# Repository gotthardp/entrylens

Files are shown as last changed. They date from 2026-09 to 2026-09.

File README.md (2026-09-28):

# Entrylens

A door-mounted people-counting sensor using a VL53L8CX time-of-flight sensor and RAK3172 (STM32WLE5)
to detect and count people and report the counts over LoRaWAN (EU868).

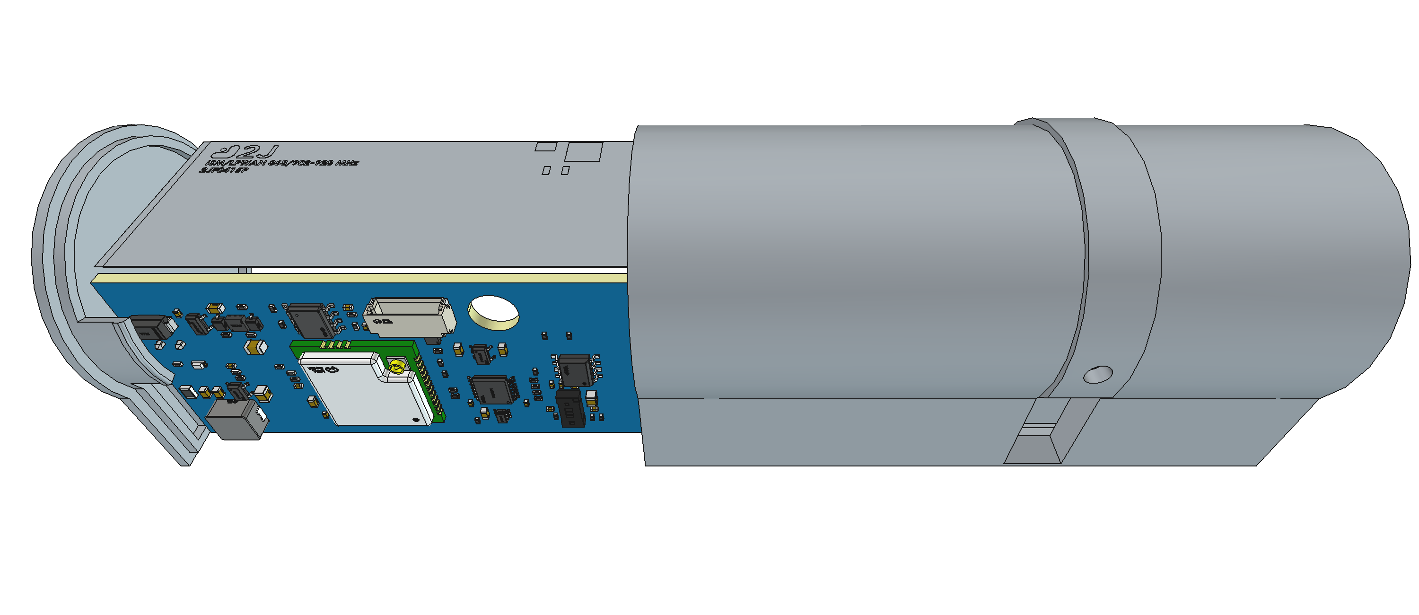
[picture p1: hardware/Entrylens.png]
Visualization


## Hardware

The design documentation is provided in [DESIGN.md](hardware/DESIGN.md).

The electronics are designed in [EasyEDA Pro](https://pro.easyeda.com) with assistance from
Claude Code (Anthropic), [pcba-design-skills](https://github.com/Keitark/pcba-design-skills), and
[pcb-checklist](https://github.com/azonenberg/pcb-checklist).

The enclosure is designed in [FreeCAD](https://www.freecad.org).

The PCB can be manufactured through [JLCPCB](https://jlcpcb.com), and the enclosure through
[JLC3DP](https://jlc3dp.com/). The reproduction cost is approximately USD 40 per unit in a small
production batch of approximately 20 units.

## Firmware

In development.

## License

Hardware design files are licensed under [CERN-OHL-W](https://cern-ohl.web.cern.ch).

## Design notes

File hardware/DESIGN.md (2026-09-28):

# Design

This document covers design intent, architecture, and components of the Entrylens sensor. Exact
passive values, pin assignments and net connectivity are in the netlist/BOM.

Visualization

## 1. Intended Use

Entrylens is an indoor people-counting sensor for museums and exhibition areas. One unit is
installed at each door opening; it counts pedestrian traffic and transmits the counts wirelessly
for occupancy calculation and analysis.

The device is intended for professional installation by technical personnel responsible for
building or museum technology.

It is an open-hardware reference design, intended to support subsequent conformity assessment and
reproduction for own use.

The target reproduction cost is about USD 40 per unit, assuming a small batch of about 20 units.

## 2. Usage

This section defines the deployment conditions, operating envelope and functional limitations of
the device. Sections 3-5 describe how they are met.

### 2.1 Deployment

The device is mounted centrally on the lower rear edge of the head jamb, opposite the door leaf,
and secured with 15 mm wide double-sided adhesive tape.

The aperture must not receive direct sunlight, as ambient infrared reduces the ranging accuracy.

The 45 degree field of view covers a 2.07 m wide strip at 250 cm mounting height; mounting lower
narrows it proportionally. The reference installation was tested on a double-leaf doorway, 250 cm
high and 130 cm wide.

The device is continuously powered over a two-wire cable from an external DC supply. The supply
must provide a SELV output, 5 V nominal, rated between 500 mA and 2 A; the 2 A maximum limits the
fault current in the cable. The cable may be up to 20 m long and must have 0.33 mm2 (22 AWG)
copper conductors, which keeps the input above the 3.5 V minimum. Copper-clad aluminium must not
be used.

Wireless network credentials are configured from a mobile application and transferred over NFC-V
(ISO/IEC 15693). The configuration is protected by a 64-bit password and remains accessible when
the device is unpowered.

### 2.2 Operation

The device continuously detects and counts people entering and leaving, using a distance-measuring
sensor; it captures no images or other visual data.

The device is designed for bidirectional traffic of individuals and groups of up to two people
abreast, walking at up to 1.5 m/s. Under the specified operating conditions the target counting
accuracy is 95 %.

The design service life is 10 years of continuous operation.

A two-colour (red/green) status LED, controlled by the MCU, is visible from outside the
enclosure. A red power LED is visible only with the lid removed.

The antenna must remain connected whenever the board is powered; powering the RAK3172 with the
U.FL connector unmated may damage its RF section.

### 2.3 Maintenance

No routine physical maintenance is required. Firmware updates and diagnostics can be performed
remotely where wireless connectivity is available.

### 2.4 Service

The debug/programming connector inside the enclosure gives access to detailed device status and is
used for troubleshooting, firmware updates and production programming. It is not connected during
normal operation.

The debug connector must not be used to power the device; the debugger's target power output must
be disabled.

Labelled test pads on the top side give probe access to +5V, +3V3, +1V8, the switched sensor
supply (+3V3_TOF, at the sensor), the eFuse FAULT signal and GND (two pads).

### 2.5 Operating environment

The device is designed for indoor use in ordinary environments such as museums and exhibition
spaces. It is not intended for industrial environments or hazardous areas.

- Temperature: 0 to 40 C
- Relative humidity: 10 to 90 % RH, non-condensing
- Vibration/shock: none expected
- Ingress protection: none declared

## 3. Mechanical

### 3.1 Composition

The device is composed of:
- an enclosure made from Nylon PA12S, modelled in `EntrylensHousing.FCStd`
- the PCB, described in Section 4
- a light pipe (FIX-LEMB3-5V0-F) that makes the red/green status LED visible from outside
- an 868 MHz antenna board (2JF0415P), whose 100 mm U.FL/IPEX cable connects directly to the
  RAK3172

### 3.2 Arrangement

The enclosure is a compact cylinder, 85 mm x 40 mm, with a removable lid for access to the
electronics. There are no external antennas or other protruding parts; only the power cable
enters, through a strain relief.

The VL53L8CX looks vertically down through a tapered aperture in the enclosure wall.

The 82 mm x 29 mm PCB and the antenna board are mounted perpendicular to each other. Both are
retained by rails that engage the clear keepout areas along the long edges of the PCB, rather than
by mounting holes or screws.

A 6 mm non-plated hole in the PCB gives clearance for the U.FL/IPEX cable from the RAK3172 to the
antenna board.

## 4. Hardware

### 4.1 Architecture

The PCB integrates the following functional blocks:
- Power input
  - 2-pin JST XH connector (B2B-XH-A(LF)(SN))
  - Input protection chain, described in Section 4.2
  - 3.3 V buck converter (TLV62569)
  - Ferrite bead (MPZ2012S331ATD25) filtering high-frequency noise
- MCU and LoRaWAN transceiver module (RAK3172, based on STM32WLE5)
- Debug/programming interface
  - 7-pin JST SR connector (SM07B-SRSS-TB)
  - ESD protection (GMF05LC-HSF)
- 4 Mbit NOR flash (P25Q40SH)
- Voltage and logic level conversion to 1.8 V
  - 1.8 V LDO regulator (MIC5504) with output discharge, switched by the MCU
  - 4-channel level shifter (LSF0204)
- ToF ranging sensor (VL53L8CX)
  - AVDD load switch (TPS22919), switched by the MCU
- Dynamic NFC/RFID tag (ST25DV04KC) with a 512-byte EEPROM
  - Antenna coil on PCB (ST25DV_Discovery_ANT_C6)
- Two LEDs: a power indicator (KT-0603R) and a status indicator (LTST-C295KGKRKT)

The LoRa antenna is placed away from the NFC antenna coil to minimize coupling.

### 4.2 Power

The device is powered over a cable up to 20 m long, so the input stage is built to survive
miswiring and cable transients. It operates from 3.5 to 5.5 V, which covers a 5 V supply's
tolerance, and withstands +/- 9 V of wrong polarity or overvoltage for at least 1 h.

The input protection chain, in order:

| Part | Function |
|---|---|
| SMAJ10CA | Input surge absorption |
| AO3401A | Reverse-polarity block |
| BZX384-C6V2 | AO3401A Vgs clamp |
| BZX384-C6V2 | Holds TPS25200 EN below its 7 V rating through the +/- 9 V withstand |
| TPS25200 | Overcurrent, overvoltage and overtemperature protection |

The TPS25200 EN pull-up is stronger than the datasheet value, so leakage cannot pull EN below its
threshold at 3.5 V in.

TPS25200 FAULT disables the TLV62569 during overcurrent, overtemperature or overvoltage lockout.
The FAULT pull-up sits on the TPS25200 output rather than on +3V3, so losing that output also
removes the TLV62569 enable, even if FAULT fails to assert.

| Rail | Nominal | Worst case | Bound by |
|---|---|---|---|
| +5V | clamped 5.25 - 5.55 V | | TPS25200 output clamp |
| +3V3 | 3.288 V | 3.212 - 3.365 V | VL53L8CX AVDD 3.13 - 3.47 V |
| +3V3_TOF | | 3.178 - 3.422 V | VL53L8CX AVDD 3.13 - 3.47 V |
| +1V8 | 1.800 V | 1.703 - 1.858 V | VL53L8CX 1.62 - 1.98 V |

The +3V3_TOF worst case adds the TLV62569 light-load rise (+1.7 %, typical curve) and the drops
through the ferrite bead and the TPS22919; the TLV62569 feedback resistors are therefore 0.1 %
parts. The +1V8 worst case uses the MIC5504 +/- 3 % over temperature plus its full-range load and
line regulation.

The RAK3172 monitors +5V through an ADC divider.

The +1V8 rail is enabled by an MCU GPIO with a pull-down, so it stays off until firmware enables
it and can be cycled. When disabled, the MIC5504 actively discharges the rail. Its turn-on time
(125 us max at 1 uF) meets the VL53L8CX minimum supply slew rate; the rail carries more than 1 uF
including local decoupling, so the ramp is confirmed at bring-up.

Firmware must configure the 1.8 V side GPIOs before enabling the rail, because the LSF0204 has no
internal pull-ups.

FAULT is not asserted while only the TPS25200 output clamp is engaged. Between the clamp and the
overvoltage lockout (6.8 - 8.45 V in), the device keeps running with +5V held at 5.4 V. The
TLV62569 input then reaches 5.55 V, over its 5.5 V recommended maximum but inside its 6 V limit;
this is accepted for a fault condition.

| Input at lockout | TPS25200 dissipation | TJ at 40 C |
|---|---|---|
| 6.8 V  | 0.30 W | 60 C |
| 8.45 V | 0.66 W | 84 C |

The device is continuously active in normal operation and does not use deep-sleep modes.

The peak current budget below treats VL53L8CX ranging and RAK3172 transmission as concurrent:

| Component | +3V3 | +1V8 |
|---|---|---|
| VL53L8CX | 60 mA  | 100 mA |
| RAK3172 | 120 mA | |
| P25Q40SH | 4 mA | |
| ST25DV04KC | 1 mA | |
| KT-0603R | 12 mA  | |
| LTST-C295KGKRKT | 22 mA  | |
| Total | 219 mA | 100 mA |

The +3V3 rail supplies 319 mA including +1V8, against a TPS25200 current limit of 428 mA
(366 - 495 mA).

At its 100 mA share the MIC5504 runs at TJ 78 - 82 C, against a 125 C limit.

### 4.3 MCU (RAK3172)

BOOT0 is not connected, and the design does not rely on RAK's undocumented internal pull-down.
Instead, option bytes nSWBOOT0 = 0 and nBOOT0 = 1, set during production programming
(Section 2.4), select boot from main flash. This disables the bootloader fallback; recovery uses
SWD.

The STM32WLE5 independent watchdog (IWDG) reboots the device if the firmware becomes unresponsive.

Brown-out reset (BOR) stays enabled. Below the BOR threshold the MCU is held in reset until the
supply recovers and then boots normally, so short interruptions and undervoltage give a clean
restart rather than degraded operation.

### 4.4 Debug/programming interface

Debugging and programming use a 7-pin JST SR connector. Its pinout is also printed on the bottom
silkscreen:

- 1: UART_RX
- 2: UART_TX (MCU output)
- 3: GND
- 4: NRST
- 5: SWCLK
- 6: SWDIO
- 7: VREF out

Either an ST-LINK or a DAPLink debugger can be used. UART2 alongside SWD provides the status access
of Section 2.4.

Pin 7 is the debugger's voltage reference only; the board is always powered from its power
connector.

The connector signals are protected as follows:

| Part | Function |
|---|---|
| GMF05LC-HSF | ESD protection of pins 1, 2 and 4-6 |
| Series resistor | Current limiting on pin 7 (VREF out) |

### 4.5 External flash (P25Q40SH)

The flash stores the VL53L8CX firmware image and, during FOTA updates, the staged MCU application
image.

/WP and /HOLD are pulled high and not MCU-controlled, so hardware write protection is unavailable.

### 4.6 ToF sensor (VL53L8CX)

The detection field of view is 45 degrees horizontally and vertically.

The enclosure aperture has no cover glass, so no crosstalk calibration is required.

An ESD clearance area surrounds the sensor aperture, so the sensor decoupling capacitors sit at its
edge rather than next to the pins.

The sensor is used in I2C mode, with the bus at 1 MHz.

The ST25DV04KC requires Rbus x Cbus below 150 ns at 1 MHz. With the fitted pull-ups this allows
45 pF on the MCU side of the LSF0204, so those traces must be kept short.

To fully reset the sensor, the MCU switches off both AVDD (through the TPS22919 load switch) and
+1V8. Both rails are actively discharged, so the 10 ms off time of UM3109 applies.

The footprint uses plain rectangular pads and deviates from ST's recommendation in two places.
Pads B1 and B7 are 0.500 mm instead of 0.535 +/- 0.030 mm, 0.005 mm beyond tolerance, which is
accepted as negligible. The thermal pad has 5 stitched vias instead of the 8 shown in AN5897,
because more do not fit the fabricator's via rules.

### 4.7 NFC (ST25DV04KC)

Energy harvesting is disabled in the device configuration, and V_EH is intentionally left
unconnected.

The antenna is a PCB coil following the ST25DV_Discovery_ANT_C6 reference design
(ANT-1-6-ST25DV):
- Turns: 15
- Size: 18.5 mm x 22.7 mm
- Trace width / spacing: 0.2 mm / 0.2 mm
- Copper: 1 oz (35 um)
- Copper beneath the coil on other layers: none
- Inductance at 13.56 MHz: 4.71 uH

### 4.8 PCB

The board has 4 layers, stacked Signal / GND / Power / Signal in JLCPCB's standard stackup: one
0.21 mm sheet of 7628 prepreg under each outer layer and a 1.065 mm core between the planes.

No trace needs controlled impedance. The 868 MHz signal leaves through the RAK3172's IPEX
connector, and the 13.56 MHz NFC coil is electrically short, so it acts as a lumped inductor.

Fabrication:
- Material: FR-4 TG135
- Thickness: 1.6 mm
- Copper: 1 oz on outer layers, as the NFC coil requires, and 0.5 oz on inner layers
- Surface finish: HASL with lead
- Vias: epoxy filled and capped, so thermal-pad vias do not draw solder from the joint
- Marking: 5 x 5 mm 2D barcode with a serial number ABCDE_0001

Assembly is SMT on the top side only; the power connector is through-hole and hand-soldered.

The VL53L8CX (MSL 3) package is not sealed, so assembly uses no-clean solder paste and no washing
(DS14161 12.6). The leaded HASL finish means leaded solder paste instead of ST's recommended
SAC305, accepted for its lower reflow peak.

Leaded solder is acceptable because RoHS does not apply (Section 6).

## 5. Software

Firmware is custom and bare-metal (no RUI3), built with STM32CubeIDE and programmed via SWD.

### 5.1 Bootloader

The bootloader checks whether a valid FOTA image is available in external flash. If so, it
installs the image and then boots the sensing application; an incomplete or invalid image is not
installed.

There is no rollback: a device that crashes immediately on boot after an update requires manual
maintenance.

### 5.2 Sensing application

The device operates as a LoRaWAN Class A device in the EU868 band. OTAA and ABP activation are
both supported; the choice is set via NFC provisioning.

Event counters are aggregated and uplinked within 5 minutes of a detection, subject to duty-cycle
limits. This window bounds the reporting latency while leaving duty-cycle margin for FOTA
downlinks.

The device keeps no synchronized wall-clock time, so events are associated with the network-server
reception timestamp rather than a precise local detection timestamp.

Counters are cumulative and volatile; no counter state is written to non-volatile memory. Any
reset or supply interruption restarts them at zero, and each uplink carries the cumulative value
and a reboot indicator so the network server can reconcile the discontinuity.

### 5.3 FOTA update

Firmware chunks received via LoRaWAN downlinks are staged in the P25Q40SH. Once a digital
signature has verified the image's authenticity and integrity, the bootloader is invoked to
install it.

## 6. Compliance

Entrylens units are built by the party that uses them, for its own use, so they are never placed
on the market (Commission Blue Guide on EU product rules, 2022/C 247/01, Section 2.3). Each unit
is only put into service, as defined in Directive 2014/53/EU (Radio Equipment Directive, RED),
Article 2(1)(11).

The RED still applies, as it also covers putting into service (RED Article 1(1)). Whoever puts a
unit into service takes on the manufacturer's responsibility for compliance and conformity
assessment (Blue Guide, Section 3.1).

Formal conformity assessment and testing have not yet been completed.

EMC immunity levels are not declared at design time; they are set at conformity assessment.
Instead, the power input is designed to tolerate what a 20 m indoor cable produces: hot-plug
ringing, coupled switching transients and miswiring.

The applicable RED essential requirements are:
- Article 3(1)(a): health and safety
- Article 3(1)(b): electromagnetic compatibility
- Article 3(2): effective and efficient use of radio spectrum

The RED Article 3(3)(d)-(f) cybersecurity requirements (Delegated Regulation (EU) 2022/30) do not
apply: the device operates on a LoRaWAN network with no internet connection and processes no
personal data.

Directive 2011/65/EU (RoHS) does not apply, because it restricts hazardous substances only in
equipment placed on the market (RoHS Article 4(1)).

Conformity is intended to be demonstrated with these harmonised standards:
- ETSI EN 300 220-2, applicable to the 863-870 MHz LoRa radio interface
- ETSI EN 300 330, applicable to the 13.56 MHz NFC interface
- ETSI EN 301 489-1 and EN 301 489-3, applicable to electromagnetic compatibility

EN IEC 62368-1 may be used as a supporting safety standard, subject to confirmation of its
applicability to the final equipment configuration.

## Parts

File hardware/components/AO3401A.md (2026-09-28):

# Pin requirements: AO3401A

- References:
  - Datasheet: `AO3401A.pdf`, "Absolute Maximum Ratings" and "Electrical Characteristics" tables
- Package / orderable variant this table applies to: SOT-23, AO3401A (P-channel MOSFET)

## Per-pin requirements

3-terminal part (Gate/Drain/Source MOSFET) - beyond identifying the three terminals in the
package pinout diagram, the datasheet does not assign a distinct requirement per pin.

## Electrical limits and consumption

| Parameter | Value | Conditions |
|---|---|---|
| Drain-source voltage (VDS) | -30 V | Absolute maximum |
| Gate-source voltage (VGS) | +/- 12 V | Absolute maximum |
| Continuous drain current (ID) | -4 A | Absolute maximum, TA = 25 degC |
| Continuous drain current (ID) | -3.2 A | Absolute maximum, TA = 70 degC |
| Pulsed drain current (IDM) | -27 A | Absolute maximum |
| Power dissipation (PD) | 1.4 W | TA = 25 degC |
| Power dissipation (PD) | 0.9 W | TA = 70 degC |
| Junction temperature | -55 to 150 degC | Absolute maximum |
| Drain-source breakdown voltage (BVDSS) | -30 V min | ID = -250 uA, VGS = 0 V |
| Gate threshold voltage (VGS(th)) | -0.5 / -0.9 / -1.3 V (min/typ/max) | VDS = VGS, ID = -250 uA |
| Static drain-source on-resistance (RDS(ON)) | 47 / 60 mOhm (typ/max) | VGS = -4.5 V, ID = -3.5 A |
| Static drain-source on-resistance (RDS(ON)) | 60 / 85 mOhm (typ/max) | VGS = -2.5 V, ID = -2.5 A |

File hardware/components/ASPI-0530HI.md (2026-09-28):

# Pin requirements: ASPI-0530HI-2R2M-T2

- References:
  - Datasheet: `ASPI-0530HI.pdf` (Abracon ASPI-0530HI series), "Electrical Specifications" table
- Package / orderable variant this table applies to: 5.7 x 5.3 x 3.0 mm molded power inductor,
  ASPI-0530HI-2R2M-T2 (2.2 uH, M = +/-20% tolerance, row for "ASPI-0530HI-2R2")

## Per-pin requirements

2-terminal part (power inductor) - the datasheet does not assign a distinct requirement per
terminal.

## Electrical limits and consumption

| Parameter | Value | Conditions |
|---|---|---|
| Inductance | 2.2 uH | +/- 20% tolerance |
| DC resistance (DCR), typical | 29.0 mOhm | |
| DC resistance (DCR), maximum | 35.0 mOhm | |
| Saturation current (Isat) | 9.0 A | Based on inductance change, dL/Lo <= -20% |
| Temperature-rise current (Irms) | 5.5 A | Based on 40 degC typical temperature rise |
| Maximum voltage | 30 V DC | |
| Operating temperature & humidity | -55 to 125 degC | Including self-generated heat |

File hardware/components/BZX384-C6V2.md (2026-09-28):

# Pin requirements: BZX384-C6V2

- References:
  - Datasheet: `BZX384_SER.pdf` (Nexperia BZX384 series, voltage regulator diodes), Rev. 4,
    1 January 2023. Pinning in Table 2, limiting values in Table 5, thermal characteristics in
    Table 6, per-type characteristics in Table 8 (row 6V2, selection C)
- Package / orderable variant this table applies to: SOD323 (SC-76), BZX384-C6V2,115 (C = the
  approximately +/-5 % tolerance selection)

## Per-pin requirements

| Pin | Function | Requirement |
|---|---|---|
| 1 | K, cathode | The marking bar indicates the cathode. |
| 2 | A, anode | |

## Electrical limits and consumption

| Parameter | Value | Conditions |
|---|---|---|
| Working voltage (VZ) | 5.80 to 6.60 V | IZ = 5 mA, Tj = 25 degC |
| Differential resistance (rdif) | 150 Ohm max / 10 Ohm max | IZ = 1 mA / IZ = 5 mA |
| Reverse current (IR) | 3 uA max | VR = 4 V |
| Temperature coefficient (SZ) | 0.4 to 3.7 mV/K | IZ = 5 mA |
| Forward voltage (VF) | 0.9 V max / 1.1 V max | IF = 10 mA / IF = 100 mA |
| Forward current (IF) | 250 mA | Limiting value |
| Non-repetitive peak reverse current (IZSM) | 6.0 A | tp = 100 us square wave, Tj = 25 degC prior to surge |
| Total power dissipation (Ptot) | 300 mW | Tamb <= 25 degC, FR4 PCB, standard footprint |
| Junction temperature (Tj) | 150 degC | Limiting value |
| Thermal resistance | 415 K/W junction to ambient, 110 K/W junction to solder point | In free air on FR4 / cathode tab |

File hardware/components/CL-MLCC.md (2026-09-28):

# Pin requirements: Samsung CL-series MLCCs

- References:
  - Datasheet: no local PDF. Samsung Electro-Mechanics publishes per-part data online at
    `https://weblib.samsungsem.com/mlcc/mlcc-ec-data-sheet.do?partNumber=<PART>`, where `<PART>`
    is the BOM's `Manufacturer Part` with its **trailing suffix letter removed** (the BOM's
    `CL21A226MAQNNNE` is queried as `CL21A226MAQNNN`).
- Package / orderable variant this table applies to: the 0402, 0603 and 0805 chip sizes listed.

## Per-pin requirements

2-terminal part - the datasheet assigns no distinct requirement per terminal.

## Part-number structure

`CL` `21` `A` `226` `M` `A` `Q` `NNN` `E`

| Field | Chars | Meaning | Codes seen |
|---|---|---|---|
| Series | `CL` | Samsung general-purpose MLCC | - |
| Case | 2 digits | EIA size | `05` = 0402, `10` = 0603, `21` = 0805 |
| Dielectric | 1 | Temperature characteristic | `A` = X5R, `B` = X7R, `C` = C0G |
| Capacitance | 3 | Two significant digits then decade exponent, in pF | `103` = 10 nF, `475` = 4.7 uF, `226` = 22 uF |
| Tolerance | 1 | EIA code | `J` = +/-5%, `K` = +/-10%, `M` = +/-20% |
| Rated voltage | 1 | | `Q` = 6.3 V, `P` = 10 V, `O` = 16 V, `A` = 25 V, `B` = 50 V |
| Thickness | 1 | | `5` = 0.50 mm, `8` = 0.80 mm, `Q` = 1.25 mm |
| Remainder | 4 | Not determined | `NNNC`, `NNNE`, `NRNC` observed |

So rated voltage is readable straight from the BOM's `Manufacturer Part` column without fetching
anything. Two traps: `Q` means 6.3 V in the voltage position but 1.25 mm in the thickness position
that follows it, and `A` and `B` mean dielectrics in one position and voltages in another.

This table was derived by decoding nine part numbers against their fetched data - the seven below
plus CL05C100JB5NNNC (10 pF C0G, the former C1, source of the `C` and `J` codes) and
CL10A475KO8NNNC (4.7 uF 16 V 0603, the former C16) - not transcribed
from a Samsung numbering guide. Every field is consistent across all nine, but codes outside those
listed are unverified - fetch the part rather than extrapolate.

## Electrical limits and consumption

Rated voltage is the figure worth pinning down: the BOM records capacitance and case size but not
voltage, and DC-bias derating scales with the fraction of rated voltage actually applied.

| Manufacturer Part | Value | Tol. | Dielectric | Case | Rated voltage |
|---|---|---|---|---|---|
| CL05B103KB5NNNC | 10 nF | +/-10% | X7R | 0402 | 50 V |
| CL05B104KO5NNNC | 100 nF | +/-10% | X7R | 0402 | 16 V |
| CL10A105KB8NNNC | 1 uF | +/-10% | X5R | 0603 | 50 V |
| CL10A226MQ8NRNC | 22 uF | +/-20% | X5R | 0603 | 6.3 V |
| CL10A106KP8NNNC | 10 uF | +/-10% | X5R | 0603 | 10 V |
| CL21A226MAQNNNE | 22 uF | +/-20% | X5R | 0805 | 25 V |
| CL21A475KAQNNNE | 4.7 uF | +/-10% | X5R | 0805 | 25 V |

The online datasheet states "Graphs for the item are not supported", so it publishes no DC-bias
curve. Rated voltage is therefore the only derating indicator the vendor provides.

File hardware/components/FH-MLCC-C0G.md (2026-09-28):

# Pin requirements: Fenghua C0G MLCCs

- References:
  - Datasheet: `MLCC-NPO.pdf` (Guangdong Fenghua, www.fenghua.com, "MLCC - NPO (COG)", 5 pages).
    The document carries no revision or date. How to Order (page 1), size code, capacitance and
    voltage table (page 3), dielectric characteristics and test methods (page 4)
- Package / orderable variant this table applies to: 0402 (1005 metric), 0402CG330J500NT (C1)

## Per-pin requirements

2-terminal part - the datasheet assigns no distinct requirement per terminal.

## Part-number structure

`0402` `CG` `330` `J` `500` `N` `T`

| Field | Chars | Meaning | Code in C1 |
|---|---|---|---|
| Size | 4 digits | EIA size | `0402` |
| Dielectric | 2 | `CG` = C0G (NPO) | `CG` |
| Capacitance | 3 | Two significant digits then decade exponent, in pF | `330` = 33 pF |
| Tolerance | 1 | `J` = +/-5.0 % | `J` |
| Rated voltage | 3 | `500` = 50 V | `500` |
| Termination | 1 | `N` = nickel barrier, tin plating | `N` |
| Packaging | 1 | `T` = tape and reel | `T` |

## Electrical limits and consumption

| Parameter | Value | Conditions |
|---|---|---|
| Capacitance | 33 pF +/-5 % | 25 degC, 1.0 V, 1 MHz |
| Rated voltage | 50 V | 0402 C0G at 50 V is offered from 1 pF to 220 pF |
| Dissipation factor | 0.15 % max | C < 1000 pF, 1 MHz |
| Insulation resistance | 5 x 10^10 Ohm min | At rated voltage, 60 s |
| Withstanding voltage | 3 x rated voltage | 60 s |
| Operating temperature range | -55 to 125 degC | |
| Dimensions (0402) | 1.00 +/-0.05 x 0.50 +/-0.05 x 0.50 +/-0.05 mm | L x W x T |

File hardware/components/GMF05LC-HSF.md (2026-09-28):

# Pin requirements: GMF05LC-HSF

- References:
  - Datasheet: `gmf05lc.pdf` (Vishay GMF05LC-HSF, 5-line ESD protection diode array), pinout
    diagram and BiAs-mode description
- Package / orderable variant this table applies to: LLP75-6L, GMF05LC-HSF-GS08

## Per-pin requirements

This part protects up to 5 signal/data lines (labeled L1-L5 in the datasheet) against a common
ground pin. All 5 protected pins are electrically identical per the datasheet's own
specification table (same VRWM/VBR/VC/VF/CD for every channel).

| Pin | Function | Requirement |
|---|---|---|
| 1 | Protected signal/data line (L1-L5, BiAs mode) | See note below. |
| 2 | Ground | Common ground reference for BiAs-mode protection (each protected input clamps to this pin). |
| 3 | Protected signal/data line (L1-L5, BiAs mode) | See note below. |
| 4 | Protected signal/data line (L1-L5, BiAs mode) | See note below. |
| 5 | Protected signal/data line (L1-L5, BiAs mode) | See note below. |
| 6 | Protected signal/data line (L1-L5, BiAs mode) | See note below. |

Note (pins 1, 3, 4, 5, 6): normal operating range is 0 V (ground level) to the reverse
stand-off voltage VRWM = 5 V, where the diode presents high isolation to ground. Above the
breakdown voltage VBR (6-8 V), the diode conducts and clamps to VC. Negative transients are
clamped to VF close to ground level.

## Electrical limits and consumption

| Parameter | Value | Conditions |
|---|---|---|
| Peak pulse current (IPPM) | 5 A | BiAs mode, IEC 61000-4-5, tp = 8/20 us, single shot |
| Peak pulse power (PPP) | 70 W | BiAs mode, IEC 61000-4-5, tp = 8/20 us, single shot |
| ESD immunity, contact or air discharge | +/- 30 kV | IEC 61000-4-2, 10 pulses |
| Operating (junction) temperature | -55 to 125 degC | Absolute maximum |
| Reverse stand-off voltage (VRWM) | 5 V | At IR = 1 uA |
| Reverse breakdown voltage (VBR) | 6 to 8 V | At IR = 1 mA |
| Reverse clamping voltage (VC) | 8 to 9.5 V typ/max | At IPP = 1 A, IEC 61000-4-5 |
| Reverse clamping voltage (VC) | 11.5 to 12.5 V typ/max | At IPP = IPPM = 5 A, IEC 61000-4-5 |
| Forward clamping voltage (VF) | 1.5 to 2 V typ/max | At IF = 1 A, IEC 61000-4-5 |
| Forward clamping voltage (VF) | 3.1 to 4 V typ/max | At IPP = IPPM = 5 A, IEC 61000-4-5 |
| Capacitance (CD) | 43 to 50 pF typ/max | At VR = 0 V, f = 1 MHz |
| Capacitance (CD) | 25 pF typ | At VR = 2.5 V, f = 1 MHz |

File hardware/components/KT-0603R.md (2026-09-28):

# Pin requirements: KT-0603R

- References:
  - Datasheet: `KT-0603R.pdf` (Kento Electronics), "Absolute Maximum Ratings" and "Electrical
    Optical Characteristics" tables
- Package / orderable variant this table applies to: 0603 (1.6 x 0.8 x 0.6 mm), red, KT-0603R

## Per-pin requirements

2-terminal part (single-die red LED) - the datasheet does not assign a distinct requirement per
terminal.

## Electrical limits and consumption

| Parameter | Value | Conditions |
|---|---|---|
| Forward voltage (VF) | 1.8 to 2.4 V | At IF = 20 mA |
| DC forward current | 25 mA | Absolute maximum |
| Peak forward current | 60 mA | Absolute maximum, 1/10 duty cycle, 0.1 ms pulse width |
| Reverse voltage (VR) | 5 V | Absolute maximum |
| Power dissipation (Pd) | 40 mW | Absolute maximum |
| Operating temperature range | -40 to 85 degC | |

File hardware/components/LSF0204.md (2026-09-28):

# Pin requirements: LSF0204

- References:
  - Datasheet: `lsf0204.pdf`, SLVSCP5H (revised April 2021). Pin table 6-1; ratings 7.1 to 7.3;
    characteristics 7.5, 7.6; block diagram 9.2; power-down 9.3.5; function table 9-1; enable and
    reference guidelines 10.2.1.1.1 (Table 10-2); I2C application Figure 10-1; section 11.
  - LSF family application note: `slva675b.pdf` (section 1: theory of operation; 3: pull-up
    current limit; 4: LSF020X internal resistor; 5.2: pull-up requirements; 5.6: one Vref grounded)
  - Schematic checklist for TXB, TXS and LSF translators: `spradj3.pdf` (sections 2.2 to 2.6)
- Package / orderable variant this table applies to: TSSOP-14 (PW package), LSF0204PWR. The
  LSF0204D variant has an active-low EN and is not interchangeable.

## Per-pin requirements

| Pin (PW) | Function | Requirement |
|---|---|---|
| 1 (Vref_A) | Reference supply, A side | Must be the lowest voltage level. Also supplies the EN input circuit. If Vref_A comes from an LDO, the LDO must sink the bias current from Vref_B, (Vref_B - Vref_A - 0.8 V) / 200 kOhm, or a 100 kOhm pull-down on Vref_A is recommended (SPRADJ3 2.2.1). |
| 2-5 (A1-A4) | Data port A, I/O | Channel n pairs An with Bn. |
| 6, 9 (NC) | No connection | Not internally connected. |
| 7 (GND) | Ground | |
| 8 (EN) | Enable, active high | VIH 0.7 x Vref_A, VIL 0.3 x Vref_A; must stay within 0 to Vref_A. Low = all I/O Hi-Z; "EN must be LOW to ensure the high-impedance state during power-up or power-down." TI recommends always enabled for I2C (10.2.1.1.1); Figure 10-1 drives EN from a separate 1.8 V enable signal. SPRADJ3 2.2.3: keep the device disabled until both supplies are stable. EN input transition rate 10 ns/V is typical only (7.5). |
| 10-13 (B4-B1) | Data port B, I/O | **Reverse order**: B4 is pin 10, B1 is pin 13. |
| 14 (Vref_B) | Reference supply, B side | At least Vref_A + 0.8 V; 1.0 V above Vref_A recommended. The 200 kOhm bias resistor is internal (9.2; `slva675b.pdf` section 4), so Vref_B connects directly to the B-side supply. |

No power sequencing is required (section 11; SPRADJ3 2.2.3). With Vref_A = Vref_B = 0 V, all data
pins and EN are Hi-Z (9.3.5); "if either Vref_A or Vref_B are grounded, the switch behaves as an
open circuit" (`slva675b.pdf` 5.6).

Decoupling: the LSF0204 datasheet specifies none, and its layout example (Figure 12-1) shows none.
SPRADJ3 2.2.2 recommends 0.1 uF at every supply pin for TXB, TXS and LSF alike, because
"level-shifters can draw large transient currents"; in the LSF the signal current flows between A
and B, and the Vref pins carry only bias current (ICCA + ICCB, ICCBA below).

## Operation and pull-ups

Each channel is a pass FET with its gate at Vref_A + VTH. While either side is low, both sides are
one node through ron. Above about Vref_A - 0.5 V the FET turns off: up, a B-side pull-up raises B;
down, A is clamped at Vref_A - a **weak 1**, for which "TI recommends only high-impedance loads
because very small amounts of current will cause the output voltage to drop significantly"
(`slva675b.pdf` section 1).

Pull-up requirement by direction (`slva675b.pdf` section 5.2 and SPRADJ3 2.6; "Pullups are not
required on inputs driven by push-pull devices"):

| Direction | A side (lower voltage) | B side (higher voltage) |
|---|---|---|
| Up, A drives B | only if the A driver is open-drain, or with leakage > 1 uA | always required |
| Down, B drives A | not required when translating to Vref_A if receiver leakage is < 1 uA, unless signal integrity needs one | only if the B driver is open-drain |
| Bidirectional open-drain (I2C) | required | required |

Pull-downs: SPRADJ3 2.6, "Pull-downs are not recommended as they create a voltage divider network
with the pull-ups used." A pull-down also loads the weak 1 when the far side drives high.

Pull-up current limit (`slva675b.pdf` section 3): RPU = (VPU - 0.35 V) / 0.015 A for 15 mA through
the FET.

## Electrical limits and consumption

| Parameter | Value | Conditions |
|---|---|---|
| VI, VI/O | -0.5 to 7 V | Absolute maximum |
| Continuous channel current | 128 mA | Absolute maximum |
| VI/O | 0 to 5.5 V | Recommended operating condition |
| IPASS (pass transistor current) | 64 mA | Recommended operating condition |
| TA | -40 to 125 degC | Recommended operating condition |
| Vref_A | 0.8 to 4.5 V | Table 10-2 |
| Vref_B | Vref_A + 0.8 to 5.5 V | Table 10-2 |
| VI(EN) | 0 to Vref_A | Table 10-2 |
| Vpu (pull-up supply) | 0 to Vref_B | Table 10-2 |
| ron | 8 Ohm typ | VI = 1.0 V, IO = 10 mA, Vref_A = VEN = 1.8 V, Vref_B = 3.3 V |
| ICCA + ICCB | 0.2 uA typ | Vref_B = 3.3 V, Vref_A = 1.8 V, VEN = Vref_A |
| ICCBA (Vref_B to Vref_A) | 3.5 uA max | same |
| Ioff | +/-1 uA max | Vref_A = Vref_B = 0 V |
| Cio(on) / Cio(off) | 10.5 typ, 13 max / 5 typ, 6 max pF | VEN = Vref_A / VEN = 0 |
| Translation speed, 3.3 V to 1.8 V | 100 MHz typ at <= 30 pF, 50 MHz typ at 50 pF | 7.6 |

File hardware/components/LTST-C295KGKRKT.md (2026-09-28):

# Pin requirements: LTST-C295KGKRKT

- References:
  - Datasheet: `LTST-C295KGKRKT.PDF` (LITE-ON), "Devices" table (pin assignment) and "Absolute
    Maximum Ratings" / "Electrical / Optical Characteristics" tables
- Package / orderable variant this table applies to: SMD-4P, LTST-C295KGKRKT (dual-die,
  green + red)

## Per-pin requirements

| Pin | Function | Requirement |
|---|---|---|
| 1 (anode), 3 | Green die (AlInGaP) | |
| 2 (anode), 4 | Red die (AlInGaP) | |

## Electrical limits and consumption

| Parameter | Value | Conditions |
|---|---|---|
| Forward voltage (VF), green die | 2.0 typ / 2.4 max V | At IF = 20 mA |
| Forward voltage (VF), red die | 2.0 typ / 2.4 max V | At IF = 20 mA |
| DC forward current, each die | 30 mA | Absolute maximum |
| Peak forward current, each die | 80 mA | Absolute maximum, 1/10 duty cycle, 0.1 ms pulse width |
| Reverse voltage, each die | 5 V | Absolute maximum |
| Power dissipation, each die | 75 mW | Absolute maximum |
| Operating temperature range | -30 to 85 degC | |

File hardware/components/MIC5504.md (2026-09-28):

# Pin requirements: MIC5504

- References:
  - Datasheet: `MIC5501-02-03-04-300mA-Single-Output-LDO-in-Small-Packages-DS20006006.pdf`,
    DS20006006C. Ratings and electrical characteristics in section 1.0 (bold values apply over
    TJ = -40 to 125 degC, the others at 25 degC only); pin table 3-1; capacitors, no-load
    stability and enable in section 4.0; SOT23-5 drawing C04-091-6BX in section 7.0.
  - LDO parameter definitions (general, not part-specific):
    `AN6030-LDO-Basics-Parameter-Definitions-Measurements-and-Calculations-DS00006030.pdf`
- Package / orderable variant this table applies to: SOT23-5 (M5), MIC5504-1.8YM5-TR (fixed
  1.8 V, auto-discharge, internal EN pull-down). The UDFN-4 (MT) variant has different pin
  numbers and an exposed pad.

## Per-pin requirements

| Pin (SOT23-5) | Function | Requirement |
|---|---|---|
| 1 (VIN) | Supply input | "An input capacitor of 1 uF is required from the input to ground to provide stability" (4.1); X5R or X7R. |
| 2 (GND) | Ground | |
| 3 (EN) | Enable, active high | High = on, low = off. Internal pull-down resistor, so the pin "may be left floating" (Table 3-1); the 4 MOhm value is typical only, so a floating EN is not guaranteed to stay below the 0.2 V logic-low limit. |
| 4 (NC) | No connection | Not internally connected. |
| 5 (VOUT) | Regulated output | "Require an output capacitor of 1 uF or greater to maintain stability"; performance is optimized for 1 uF and "does not improve significantly with larger capacitance" (4.2). Low-ESR X5R/X7R ceramic. When EN is low, an internal 25 Ohm load discharges the output capacitors. |

## Electrical limits and consumption

| Parameter | Value | Conditions |
|---|---|---|
| VIN | -0.3 to 6 V | Absolute maximum |
| VEN | -0.3 V to VIN | Absolute maximum |
| VIN | 2.5 to 5.5 V | Operating rating |
| VEN | 0 V to VIN | Operating rating |
| Output voltage accuracy | +/-2 % | 25 degC |
| Output voltage accuracy | +/-3 % | -40 to 125 degC |
| Line regulation | 0.02 typ / 0.3 max %/V | VIN = VOUT + 1 V to 5.5 V, IOUT = 100 uA, over temperature |
| Load regulation | 8 typ / 40 max mV | IOUT = 100 uA to 300 mA, 25 degC only |
| Dropout voltage | 80 typ / 190 max mV | IOUT = 150 mA, over temperature |
| Dropout voltage | 160 typ / 380 max mV | IOUT = 300 mA, over temperature |
| Ground current | 38 typ / 55 max uA | IOUT = 0 mA, over temperature |
| Ground current in shutdown | 0.05 typ / 1 max uA | VEN = 0 V |
| Current limit | 400 min / 630 typ / 900 max mA | VOUT = 0 V, 25 degC only |
| Auto-discharge resistance | 25 Ohm typ | VEN = 0 V, VIN = 3.6 V, IOUT = -3 mA |
| EN logic low | 0.2 V max | Over temperature |
| EN logic high | 1.2 V min | Over temperature |
| EN pull-down resistance | 4 MOhm typ | |
| EN input current | 0.01 typ / 1 max uA; 1.4 typ / 2 max uA | VEN = 0 V; VEN = 5.5 V |
| Turn-on time | 50 typ / 125 max us | COUT = 1 uF, IOUT = 150 mA, over temperature; the measurement end point (e.g. 90 % of VOUT) is not stated |
| Thermal resistance | 253 degC/W | SOT23-5, junction to ambient |
| Operating junction temperature | -40 to 125 degC | |
| Overall package height | 0.90 to 1.45 mm | SOT23-5 drawing C04-091-6BX |

No soft-start is specified; the output rise is set by the turn-on time above. The part is stable
with no load (4.3). No thermal shutdown threshold is given.

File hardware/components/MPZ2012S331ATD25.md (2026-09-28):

# Pin requirements: MPZ2012S331ATD25

- References:
  - Datasheet: `beads_automotive_power_mpz2012_en.pdf` (TDK MPZ2012 series, AEC-Q200),
    20190423. Characteristics Specification Table (330 Ohm row), rated current vs. temperature
    derating graph, and Z, X, R vs. frequency curve for MPZ2012S331ATD25
- Package / orderable variant this table applies to: 2012 (L x W x T = 2.0 x 1.25 x 0.85 mm),
  MPZ2012S331ATD25 (330 Ohm @ 100 MHz row)

## Per-pin requirements

2-terminal part (chip bead) - the datasheet does not assign a distinct requirement per
terminal.

## Electrical limits and consumption

| Parameter | Value | Conditions |
|---|---|---|
| Impedance | 330 Ohm +/- 25% | At 100 MHz |
| Impedance peak | About 380 Ohm near 250 MHz | Read from the Z-f curve, typical |
| DC resistance (DCR) | 0.050 Ohm max | |
| Rated current | 2.5 A max | See the datasheet's rated-current-vs-temperature derating graph for 85 degC and above |
| Operating temperature range | -55 to 125 degC | |

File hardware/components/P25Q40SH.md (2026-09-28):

# Pin requirements: P25Q40SH

- References:
  - Datasheet: `P25Q40SH_Datasheet_V1.9.pdf`, revision V1.9, pin table in section 3.2,
    status/configure registers in section 7
  - Suggested land pattern for the SOP8 150-mil outline, which the datasheet does not give:
    `AN0000009 SpiFlash PCB Layout Guideline v2.1 06122020.pdf`
- Package / orderable variant this table applies to: SOP8 150-mil, P25Q40SH-SSH-IT (tube
  packing; the tape-and-reel variant is P25Q40SH-SSH-IR)

## Per-pin requirements

| Pin | Function | Requirement |
|---|---|---|
| 1 (CS#) | Chip select, input | Active low. Must not float - a low level selects the device. A 10 kOhm pullup keeps the part deselected while the controller's I/O is still tri-stated during reset and boot. |
| 2 (SO / SIO1) | Serial data output, or bidirectional I/O | Standard SPI: data output. Dual/Quad: bidirectional SIO1. |
| 3 (WP# / SIO2) | Write protect, input; or bidirectional I/O | Active low, protects the Status Register in conjunction with the block-protect and SRP bits. **Available only when QE = 0, which is the factory default.** If QE is set to 1 the pin becomes data I/O SIO2 and the write-protect function is lost. A pullup keeps write protection deasserted; a low level is an unexpected hardware-protect state. |
| 4 (GND) | Ground | |
| 5 (SI / SIO0) | Serial data input, or bidirectional I/O | Standard SPI: data input. Dual/Quad: bidirectional SIO0. |
| 6 (SCLK) | Serial clock, input | Provides timing for serial input and output. |
| 7 (HOLD# / RESET# , SIO3) | Hold or Reset, input; or bidirectional I/O | Function selected by the non-volatile HOLD/RST bit in the Configure Register: **HOLD/RST = 0 (factory default) makes the pin /HOLD**; HOLD/RST = 1 makes it /RESET. Both are active low, and **both are available only when QE = 0**. If QE is set to 1 the pin becomes data I/O SIO3 and both functions are disabled. A pullup keeps whichever function is selected deasserted. |
| 8 (VCC) | Power supply | |

Notes from the datasheet worth carrying forward:

- Section 7: "The Quad Enable (QE) bit is a non-volatile Read/Write bit in the Status
  Register that allows Quad operation. When the QE bit is set to 0 (Default) the WP# pin
  and HOLD# pin are enable. When the QE pin is set to 1, the Quad IO2 and IO3 pins are
  enabled." QE is a writable bit with a **default of 0**, so WP# and HOLD# are available as
  received.
- Same section: "The QE bit should never be set to 1 during standard SPI or Dual SPI"
  operation when WP#/HOLD# are hard-tied - a pullup rather than a direct tie leaves this
  safe either way.
- The HOLD/RST bit offers a hardware /RESET input on pin 7 as an alternative to /HOLD. Using
  it would require the controller to drive that pin, which a 2-wire SPI connection does not.

## Electrical limits and consumption

| Parameter | Value | Conditions |
|---|---|---|
| VCC (operating) | 2.3 to 3.6 V | Read, erase and program |
| Ambient operating temperature | -40 to +85 degC | Device grade I |
| Deep power-down current (IDPD) | 0.2 typ / 2.5 max uA | CS# = VCC, all other inputs at 0 V or VCC |
| Read current (ICC1) | 2.0 typ / 2.5 max mA | f = 33 MHz (03h), IOUT = 0 mA |
| Read current (ICC1) | 8 typ / 14 max mA | f = 85 MHz, IOUT = 0 mA |
| Read current (ICC1) | 10 typ / 18 max mA | f = 104 MHz, IOUT = 0 mA |
| Program current (ICC2) | 2.5 typ / 4.0 max mA | CS# = VCC |
| Erase current (ICC3) | 2.5 typ / 4.0 max mA | CS# = VCC |
| Input low voltage (VIL) | -0.5 to 0.3 x VCC | |
| Input high voltage (VIH) | 0.7 x VCC to VCC + 0.3 V | |
| Output low voltage (VOL) | 0.2 V max | IOL = 100 uA |
| Output high voltage (VOH) | VCC - 0.2 V min | IOH = -100 uA |
| Endurance | 100,000 program/erase cycles | |
| Data retention | 20 years | |

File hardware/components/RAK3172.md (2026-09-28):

# Pin requirements: RAK3172

- References:
  - Datasheet: RAK3172 module datasheet (no local PDF, available online
    https://docs.rakwireless.com/product-categories/wisduo/rak3172-module/datasheet/), pin
    definition table for the IPEX-antenna variant.
  - Electrical limits below are instead sourced from the underlying MCU's own local datasheet,
    `stm32wle5cc.pdf` (Table 23, Table 74)
  - STM32WLE5 reference manual (register-level detail, not a pin datasheet):
    `rm0461-stm32wlex-advanced-armbased-32bit-mcus-with-subghz-radio-solution-stmicroelectronics.pdf`.
    I/O state after reset in 8.3.1; SWJ debug port pins in 36.3.6.
  - Errata sheet for the underlying die, ES0506 Rev 5, March 2023:
    `es0506-stm32wle5xx-stm32wle4xx-device-errata-stmicroelectronics.pdf`. Status letters below are
    A = workaround available, P = partial, N = none.
  - Schematic design guide:
    https://learn.rakwireless.com/hc/en-us/articles/32403676739607-how-to-design-schematic-for-rak3172-lorawan-module
  - Clarification that BOOT0 is pulled down internally by the module (RAK staff, forum):
    https://forum.rakwireless.com/t/rak3172-does-not-work/8475
  - External 868 MHz antenna mating the module's IPEX connector: `2jf0415p.pdf`
- Package / orderable variant this table applies to: RAK3172-SM with IPEX antenna connector,
  RAK3172-8-SM-I (32-pin SMD module)

## Per-pin requirements

| Pin | Name | Requirement |
|---|---|---|
| 1 | PA3/UART2_RX | Reserved - UART2/LPUART1 interface (AT commands and firmware update). |
| 2 | PA2/UART2_TX | Reserved - UART2/LPUART1 interface (AT commands and firmware update). |
| 3 | PA15/PIN_A4 | GPIO and ADC. **JTAG JTDI**: input with internal pull-up after reset, until firmware reconfigures it; usable as GPIO once firmware selects SWD-only. |
| 4 | PB6/UART1_TX | UART1 interface. |
| 5 | PB7/UART1_RX | UART1 interface. |
| 6 | PA1 | GPIO only. |
| 7 | PA13/SWDIO | Reserved - SWD debug pin (SWDIO); JTAG JTMS. Input with internal pull-up after reset. |
| 8 | PA14/SWCLK | Reserved - SWD debug pin (SWCLK); JTAG JTCK. Input with internal pull-down after reset. |
| 9 | PA12/I2C_SCL | GPIO and I2C (SCL). |
| 10 | PA11/I2C_SDA | GPIO and I2C (SDA). |
| 11 | GND | Ground. |
| 12 | RF  | RF Port, not available on IPEX variant. |
| 13 | PA7 | SPI1 (MOSI). |
| 14 | PA6 | SPI1 (MISO). |
| 15 | PA5 | SPI1 (CLK). |
| 16 | PA4 | SPI1 (NSS). |
| 17 | GND | Ground. |
| 18 | GND | Ground. |
| 19 | PA8 | GPIO only. |
| 20 | PA9 | GPIO only. |
| 21 | BOOT0 | Boot0 mode enable pin, high active (MCU pin PH3-BOOT0). Per a RAK staff forum clarification (see header above), BOOT0 is pulled down internally by the module - no external strap is required. The pin is an input during reset until at least the end of option-byte loading; option bytes nSWBOOT0 = 0 and nBOOT0 = 1 make the boot selection ignore it. |
| 22 | RST | MCU reset (NRST). |
| 23 | GND | Ground. |
| 24 | VDD | Voltage supply. |
| 25 | PA10/PIN_A3 | GPIO and ADC. |
| 26 | PB2/PIN_A2 | GPIO and ADC. |
| 27 | PB12 | 10 kOhm internally pulled up for the high-frequency variant, or pulled down for the low-frequency variant. |
| 28 | GND | Ground. |
| 29 | PA0 | GPIO only. |
| 30 | PB5 | GPIO only. |
| 31 | PB4/PIN_A1 | GPIO and ADC. **JTAG NJTRST**: input with internal pull-up after reset, until firmware reconfigures it; usable as GPIO once firmware selects SWD-only. The pull-up makes it unsuitable for a signal that must be low before firmware runs. |
| 32 | PB3/PIN_A0 | GPIO and ADC. **JTAG JTDO / TRACESWO**: Hi-Z, no pull after reset; usable as GPIO once firmware selects SWD-only. Becomes an output if a debugger enables single-wire trace (SWO). |

I/O state after reset (RM0461 8.3.1): "most of the I/O ports are configured in analog mode" (no
pull). The exceptions are the five SWJ debug pins noted above (PA13, PA14, PA15, PB3, PB4), which
are in debug alternate-function mode with the pulls listed, and PH3-BOOT0 (pin 21).
JTAG is selected by default after reset; in SW-DP mode "the unused JTAG pins JTDI, JTDO and nJTRST
can be used for other functions" (36.3.6), and reconfiguring PA13/PA14 disables debugging. The
internal weak pull-up/pull-down is 25 to 55 kOhm (`stm32wle5cc.pdf`, I/O static characteristics,
RPU/RPD).

## Electrical limits and consumption

| Parameter | Value | Conditions |
|---|---|---|
| VDD (main supply voltage) | -0.3 to 3.9 V | Absolute maximum |
| VDD (standard operating voltage) | 2.0 to 3.6 V | Recommended operating condition |
| Operating current, TX | 87 mA to 120 mA | 868 MHz; 87 mA at 20 dBm (RAK module datasheet), 120 mA at +22 dBm (`stm32wle5cc.pdf` Table 29, radio only, typ) |
| Operating current, RX | 5.22 mA | |
| VOH (output high level) | >= VDD - 0.4 V | CMOS port, IIO = 8 mA, VDD >= 2.7 V |
| VOH (output high level) | >= 2.4 V | TTL port, IIO = 8 mA, VDD >= 2.7 V |
| VOH (output high level) | >= VDD - 1.3 V | IIO = 20 mA, VDD >= 2.7 V |
| VOL (output low level) | <= 0.4 V | CMOS port, IIO = 8 mA |
| VOL (output low level) | <= 1.3 V | IIO = 20 mA |
| Output current sunk by any I/O or control pin | 20 mA | Absolute maximum |
| Output current sourced by any I/O or control pin | 20 mA | Absolute maximum |
| Total output current sunk, sum of all I/Os and control pins | 100 mA | Absolute maximum, must be distributed over all I/Os |
| Total output current sourced, sum of all I/Os and control pins | 100 mA | Absolute maximum, must be distributed over all I/Os |
| Operating temperature range | -20 to 85 degC | |

## Known limitations of the STM32WLE5 die (ES0506 Rev 5)

The module datasheet carries no errata of its own; these are limitations of the STM32WLE5 inside it.
Only the ones this design can hit are listed. Status is given for silicon Rev Z and Rev Y; the
module's silicon revision is not stated by RAK and has not been confirmed.

| Section | Status | Limitation | Workaround |
|---|---|---|---|
| 2.7.1 | P / P | Wrong data sampling when the I2C data setup time tSU;DAT is shorter than one I2C kernel clock period: the previous SDA value is sampled instead of the current one, giving a wrong target address, data byte or acknowledge bit | Raise the I2C kernel clock so its period fits inside the transmitter's minimum setup time. **In Fast-mode Plus, for the standard 50 ns minimum, I2CCLK must be at least 20 MHz** (Fast mode 10 MHz, Standard mode 4 MHz) |
| 2.2.6 | A / A | The 1.2 V regulated supply can dip to 1.08 V when MSI steps from 400 kHz to 24 MHz or above, or from 1 MHz to 48 MHz, which can cause a CPU HardFault. Reached by way of 2.7.1, which forces a higher kernel clock | Step through an intermediate MSI frequency, e.g. 400 kHz -> 12 MHz -> 48 MHz |
| 2.2.2 | N / N | Re-programming a flash location that currently holds all ones with all zeros fails and sets PROGERR. Erased locations are unaffected | None. Avoid all-zeros-over-all-ones as a marker pattern |
| 2.2.5 | A / A | FLASH_ECCR can be corrupted if a reset or power-down happens during a flash program or erase and the same location is then read | Erase the page(s) covering that location |
| 2.2.14 | A / A | TX spurs around the carrier at multiples of the HSE clock frequency | See ES0506. Bears on EN 300 220 spurious emissions |
| 2.2.18 | A / A | Packet loss with inverted IQ operation, which LoRaWAN downlinks use by specification | See ES0506 |

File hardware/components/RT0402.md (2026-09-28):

# Pin requirements: YAGEO RT0402 thin-film resistors

- References:
  - Datasheet: `PYU-RT_1-TO-0-01_ROHS_L.pdf` (YAGEO RT series, thin film chip resistors, 0.01 %
    to 1 %, TCR 5 to 50), product specification February 12, 2026 V.17. Ordering information
    (page 2), Table 2 electrical characteristics (page 5), rated-power derating (Fig. 6)
- Package / orderable variant this table applies to: 0402, RT0402BRD0744K8L (R3, 44.8 kOhm),
  RT0402BRD07226KL (R4, 226 kOhm), RT0402BRD0710KL (R5, 10 kOhm)

## Per-pin requirements

2-terminal part - the datasheet assigns no distinct requirement per terminal.

## Part-number structure

`RT` `0402` `B` `R` `D` `07` `44K8` `L`

| Field | Meaning | Code in this BOM |
|---|---|---|
| Series | RT, thin film | `RT` |
| Size | 0402 | `0402` |
| Tolerance | `B` = +/-0.1 % | `B` |
| Packaging | `R` = paper/PE taping reel | `R` |
| Temperature coefficient | `D` = 25 ppm/degC | `D` |
| Taping reel | `07` = 7 inch | `07` |
| Resistance | Letter marks the decimal point | `44K8`, `226K`, `10K` |
| Default code | Order only | `L` |

## Electrical limits and consumption

| Parameter | Value | Conditions |
|---|---|---|
| Tolerance | +/-0.1 % | Code B |
| Temperature coefficient (TCR) | +/-25 ppm/degC | Code D |
| Resistance range | 4.7 Ohm to 240 kOhm | RT0402, +/-0.1 %, +/-25 ppm/degC (Table 2). 44.8 kOhm is an E-192 value ("on request"); 10 kOhm and 226 kOhm are E-24/E-96 |
| Rated power | 1/16 W | At 70 degC, derated above (Fig. 6) |
| Maximum working voltage | 50 V | Continuous, IEC 60115-8 |
| Maximum overload voltage | 100 V | |
| Operating temperature range | -55 to 155 degC | Table 2, cell shared by RT0402 to RT1206 |
| Life / endurance | +/-(0.5 % + 0.05 Ohm) | 1000 h at 70 degC, rated voltage |

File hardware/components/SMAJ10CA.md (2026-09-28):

# Pin requirements: SMAJ10CA

- References:
  - Datasheet: `Littelfuse-TVS-Diode-SMAJ-Datasheet.pdf` (Littelfuse SMAJ series), revised
    12/02/25 V.1. "Maximum Ratings and Thermal Characteristics" table and "Electrical
    Characteristics" table (row SMAJ10CA, single-die part)
- Package / orderable variant this table applies to: DO-214AC (SMA), Littelfuse SMAJ10CA
  (bidirectional TVS)

## Per-pin requirements

2-terminal part (bidirectional TVS diode) - the datasheet does not assign a distinct
requirement per terminal. Bidirectional parts carry no cathode band.

## Electrical limits and consumption

| Parameter | Value | Conditions |
|---|---|---|
| Reverse stand-off voltage (VR) | 10.0 V | - |
| Breakdown voltage (VBR) | 11.10 to 12.30 V | At test current IT = 1 mA, TA = 25 degC |
| VBR temperature coefficient | 0.1 %/degC typ | VBR at TJ = VBR at 25 degC x (1 + aT x (TJ - 25)) |
| Maximum clamping voltage (VC) | 17.0 V | At peak pulse current IPP = 23.5 A |
| Maximum peak pulse current (IPP) | 23.5 A | 10/1000 us waveform |
| Maximum reverse leakage current (IR) | 5 uA | At VR |
| Peak pulse power dissipation (PPPM) | 400 W | 10/1000 us waveform, TA = 25 degC, non-repetitive, mounted on 5.0 x 5.0 mm copper pad per terminal; derated above TJ = 25 degC |
| Power dissipation (PD) | 3.3 W | Infinite heat sink, TL = 50 degC |
| ESD immunity (IEC 61000-4-2) | 30 kV air / 30 kV contact | Device-level rating |
| Operating junction temperature | -65 to 150 degC | |
| Thermal resistance | 30 degC/W junction to lead, 120 degC/W junction to ambient | Typical |

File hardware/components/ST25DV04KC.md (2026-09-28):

# Pin requirements: ST25DV04KC

- References:
  - Datasheet: `st25dv04kc.pdf` (DS13519 Rev 8), Table 1 (8-pin packages signal names), section 2
    (Signal descriptions), Table 249 (I2C DC characteristics up to 85 degC), Table 251 and
    Figure 82 (I2C AC characteristics, pull-up sizing at 1 MHz)
  - Energy harvesting / V_EH behavior during RF communication (app note):
    `an4913-energy-harvesting-delivery-impact-on-st25dvi2c-series-behaviour-during-rf-communication-stmicroelectronics.pdf`
  - I2C bus pull-up resistor sizing (TI app note, shared bus with VL53L8CX): `slva689.pdf`
  - Errata sheet ES0617 Rev 5, April 2026 (device limitations, all ST25DVxxKC):
    `es0617-st25dv04kc-st25dv16kc-and-st25dv64kc-device-limitations-stmicroelectronics.pdf`
  - ST reference antenna artwork for the AC0/AC1 coil (net `ANT-C6`): `ant_c6_gerber.zip`
    (ST25DV-ANT-C6-REV-A Gerbers)
- Package / orderable variant this table applies to: SO8N, ST25DV04KC-IE8S3 (8-pin package;
  the 10-ball/12-pin packages add an LPD pin and a CMOS-type GPO with a VDCG supply pin, not
  covered here)

## Per-pin requirements

| Pin | Function | Requirement |
|---|---|---|
| 1 (V_EH) | Energy harvesting analog output | Delivers the analog V_EH voltage when energy harvesting mode is enabled and RF field strength is sufficient. When energy harvesting is disabled, or RF field strength is insufficient, this pin is high-Z. Output is not regulated. |
| 2 (AC0) | Antenna coil, RF | Connect to the external antenna coil. Do not connect to any other DC or AC path. |
| 3 (AC1) | Antenna coil, RF | Connect to the external antenna coil. Do not connect to any other DC or AC path. |
| 4 (VSS) | Ground | Reference for VCC, VDCG (not present on this package), and V_EH. |
| 5 (SDA) | Serial data, I/O | Bidirectional, open-drain output, may be wire-OR'ed with other open-drain/open-collector signals on the bus. A pullup resistor to VCC is required. |
| 6 (SCL) | Serial clock, input | Strobes data in/out. If used by target devices to synchronize to a slower clock, the bus controller must have an open-drain output and a pullup resistor must be connected from SCL to VCC. |
| 7 (GPO) | General-purpose output | Open-drain. Must be connected to an external pullup resistor (>4.7 kOhm) to operate. By default configured as an RF-field-change detector; can also flag RF activity, memory write completion, or fast-transfer events. |
| 8 (VCC) | Supply voltage | External DC supply; an internal regulator lets external VCC supply the device while preventing the internally-rectified RF supply from driving VCC. |

## Electrical limits and consumption

| Parameter | Value | Conditions |
|---|---|---|
| VCC (I2C supply voltage) | -0.5 to 6.5 V | Absolute maximum |
| VCC (I2C operating supply voltage) | 1.8 to 5.5 V | Recommended operating condition |
| VIO (digital I/O range: SDA, SCL, GPO) | -0.5 to 6.5 V | Absolute maximum |
| DC output current on SDA (low) | 5 mA max | Absolute maximum |
| DC output current on GPO (low) | 1.5 mA max | Absolute maximum |
| RF input voltage amplitude, AC0-AC1 (peak-to-peak) | 11 V | Absolute maximum, VSS floating |
| AC voltage, AC0-VSS or AC1-VSS | -0.5 to 5.5 V | Absolute maximum |
| Ambient operating temperature, RF interface | -40 to 105 degC | Absolute maximum, device grade 8, SO8N |
| Ambient operating temperature, I2C interface | -40 to 125 degC | Absolute maximum, device grade 8, SO8N |
| Operating supply current (I2C read or write, active) | 300 uA max (280 uA typ) | VCC = 3.3 V, fC = 1 MHz, worst mode (mailbox write), up to 85 degC |
| Static standby supply current | 100 uA max (76 uA typ) | VCC = 3.3 V, up to 85 degC |
| VIL (SDA, SCL) | 0.3 VCC max | VCC = 3.3 V |
| VIH (SDA, SCL) | 0.75 VCC min | VCC = 3.3 V |
| VOL (SDA, 1 MHz) | 0.4 V max | IOL = 2.1 mA, VCC = 3.3 V (at VCC = 1.8 V the same limit holds only at IOL = 1 mA) |
| Rbus x Cbus (SDA/SCL pull-up x bus capacitance) | below 150 ns | fC = 1 MHz, Figure 82: "must be below 150 ns"; the tCLQV 450 ns access time assumes it |

## Known limitations (ES0617 Rev 5)

Only the limitations this design can hit are listed. The LPD-pin reset workaround offered for the
first one is available only on product codes 51h and 53h; the SO8N ST25DV04KC is product code 50h
and has no LPD pin, so that route does not exist for this part.

| Section | Limitation | Workaround |
|---|---|---|
| 1.1.1 | Potential RF and I2C lock if VCC is disconnected then reconnected while an RF field is present. A floating VCC under RF sits at about 1.4 V; the device leaves that state by itself if the field goes away, if any RF command arrives (VCC then falls to 0 V), or if VCC rises above 1.8 V. But a 1.4 V -> 0 V -> >1.8 V sequence can deadlock it: all I2C accesses unacknowledged, every RF command answered with error 0Fh. The trigger is a negative VCC pulse **shorter than 1 ms**, which leaves internal capacitors partly charged so the internal reset does not complete | Hold VCC at 0 V for **longer than 1 ms** before disconnecting it, or before reconnecting it. Alternatively a capacitor on VCC whose time constant exceeds the glitch filters it out |
| 1.3.1 | Sub-carrier frequency drift on a marginal portion of production parts causes a communication hole at certain field strengths; more likely as ambient temperature falls | Move the tag closer or farther; a tap gesture is less affected because the protocol retries; revision 13h parts are fixed; some readers are insensitive to the drift |
| 1.4.1 | An I2C write carrying only the system device select code and memory address 0900h, with no data byte, corrupts the internal memory address pointer, so a following I2C write can program at the wrong address | Never write address 0900h without at least one data byte. Use 0900h only to present or write passwords. Any I2C random read to a valid address resets the pointer |

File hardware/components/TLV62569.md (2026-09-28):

# Pin requirements: TLV62569

- References:
  - Datasheet: `tlv62569.pdf`, "Pin Configuration and Functions" (Pin Functions table)
  - Feedforward-capacitor sizing across the FB divider (app note SLVA289B): `slva289b.pdf`
  - Output filter: Table 4 gives the sanctioned L/COUT combinations and note (2) states that
    "Capacitance tolerance and bias voltage de-rating is anticipated. The effective capacitance can
    vary by +20% and -50%."
- Package / orderable variant this table applies to: SOT23-5 (DBV package), TLV62569DBVR - this
  package has no PG or NC pin (those exist only on the 6-pin SOT23-6/SOT563-6 variants)

## Per-pin requirements

| Pin (SOT23-5) | Function | Requirement |
|---|---|---|
| 1 (EN) | Enable, input | Logic high enables the device; logic low disables it (shutdown). Section 8.3.1: "The EN input must be terminated and should not be left floating." Thresholds in the table below. |
| 2 (GND) | Ground, power | |
| 3 (SW) | Switch, power | Connected to the internal FET switches and inductor terminal - connect the output filter's inductor to this pin. |
| 4 (VIN) | Power supply input, power | |
| 5 (FB) | Feedback, input | Connect to an external feedback divider for the internal control loop. |

## Electrical limits and consumption

| Parameter | Value | Conditions |
|---|---|---|
| VIN, EN, PG voltage | -0.3 to 6 V | Absolute maximum |
| SW voltage (DC) | -0.3 to VIN + 0.3 V | Absolute maximum |
| SW voltage (AC, pulses < 10 ns) | -3.0 to 9 V | Absolute maximum |
| FB voltage | -0.3 to 5.5 V | Absolute maximum |
| VIN | 2.5 to 5.5 V | Recommended operating condition |
| VUVLO (undervoltage lockout) | 2.3 min / 2.45 max V | VIN falling, 100 mV hysteresis |
| VIH (high-level threshold at EN) | 0.95 min / 1.2 max V | 2.5 V <= VIN <= 5.5 V |
| VIL (low-level threshold at EN) | 0.4 min / 0.85 max V | 2.5 V <= VIN <= 5.5 V |
| VOUT | 0.6 to VIN V | Recommended operating condition |
| VFB (feedback regulation voltage) | 0.588 min / 0.6 typ / 0.612 max V | |
| IOUT | 0 to 2 A | Recommended operating condition |
| Operating junction temperature | -40 to 125 degC | Recommended operating condition |
| Thermal shutdown | 150 degC rising / 130 degC falling | |
| RDS(on), high-side FET | 100 mOhm typ | - |
| RDS(on), low-side FET | 60 mOhm typ | - |
| ILIM (high-side FET current limit) | 3 A min | TLV62569DBV / TLV62569PDDC package |

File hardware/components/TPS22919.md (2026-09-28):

# Pin requirements: TPS22919

- References:
  - Datasheet: `tps22919.pdf`, SLVSEN5B, October 2018, revised May 2019. Pin table in section 5;
    ratings in 6.1 to 6.4; electrical and switching characteristics in 6.5 and 6.6; ON-pin and
    QOD behaviour in 8.3.1 and 8.3.3; supply guidance in section 10.
- Package / orderable variant this table applies to: SC-70-6 (DCK package), TPS22919DCKR

## Per-pin requirements

| Pin | Function | Requirement |
|---|---|---|
| 1 (IN) | Switch input | 1.6 to 5.5 V operating, 6 V absolute maximum. An input capacitance of 1 uF is sufficient in most cases and must be placed as close to the pin as possible; additional bulk is needed only where the supply responds slowly to a large turn-on transient. |
| 2 (GND) | Device ground | |
| 3 (ON) | Active-high switch control input | **"Do not leave floating."** VIH 1 V minimum, VIL 0.35 V maximum, so a 3.3 V GPIO drives it directly. A Smart Pull Down holds the pin low when VIN is first applied, but it disconnects permanently once the pin is driven high - see the section below. |
| 4 (NC) | No connect | Datasheet: "No connect pin, leave floating." |
| 5 (QOD) | Quick output discharge | Three sanctioned configurations: tie directly to VOUT and use the internal RPD(QOD); connect to VOUT through an external RQOD to slow the discharge; or leave floating, which disables discharge entirely and leaves the output floating after turn-off. |
| 6 (VOUT) | Switch output | 0 to 5.5 V operating, 6 V absolute maximum. |

## Electrical limits and consumption

| Parameter | Value | Conditions |
|---|---|---|
| VIN, VOUT, VON, VQOD | -0.3 to 6 V | Absolute maximum |
| IMAX (continuous current) | 1.5 A | Absolute maximum |
| IPLS (pulsed current) | 2.5 A | Absolute maximum, 2 ms at 2 % duty cycle |
| TJ | Internally limited | Absolute maximum |
| VIN (input voltage range) | 1.6 to 5.5 V | Recommended operating condition |
| VIH (ON pin high) | 1 to 5.5 V | Recommended operating condition |
| VIL (ON pin low) | 0 to 0.35 V | Recommended operating condition |
| TA (ambient) | -40 to 105 degC | Recommended operating condition |
| RON (on-state resistance) | 90 typ / 150 max mOhm | VIN = 3.6 V, IOUT = -200 mA, TJ = 25 degC |
| RON (on-state resistance) | 200 max mOhm | VIN = 3.6 V, -40 to 85 degC |
| ION (ON pin leakage) | 100 nA max | VON >= VIH, -40 to 125 degC |
| **RPD(ON) (Smart Pull Down)** | **530 kOhm typ** | VON <= VIL only - disconnected above VIH |
| **RPD(QOD) (internal discharge)** | **24 Ohm typ** | VON <= VIL |
| tR (output rise time) | 1100 us typ | VIN = 3.6 V |
| SRON (turn-on slew rate) | 2.7 mV/us | VIN = 3.6 V |
| tFALL (output fall time) | 0.4 ms | CL = 10 uF, QOD shorted to VOUT, RL open |

Self-protected: current limit, short-circuit protection and thermal shutdown. No figure from those
is used by this design.

Switching characteristics are typical values at VIN = 3.6 V, TA = 25 degC, CL = 0.1 uF and
RL = 100 Ohm unless the row says otherwise. Turn-on slew scales with input voltage: 1.8 mV/us at
1.8 V, 2.7 mV/us at 3.6 V, 3.2 mV/us at 5.0 V.
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

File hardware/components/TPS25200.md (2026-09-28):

# Pin requirements: TPS25200

- References:
  - Datasheet: `tps25200.pdf`, Table 4-1 (Pin Functions)
  - Exposed-pad land, stencil aperture and thermal via design (app note SLUA271C): `slua271c.pdf`
- Package / orderable variant this table applies to: WSON-6 (DRV package), TPS25200DRVR
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

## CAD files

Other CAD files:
hardware/EntrylensHousing.FCStd
